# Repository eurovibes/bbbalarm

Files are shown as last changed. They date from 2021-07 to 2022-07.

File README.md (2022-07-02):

<!-- SPDX-FileCopyrightText: 2021 Benedikt Spranger <b.spranger@linutronix.de> -->
<!-- SPDX-License-Identifier: CERN-OHL-S-2.0 -->


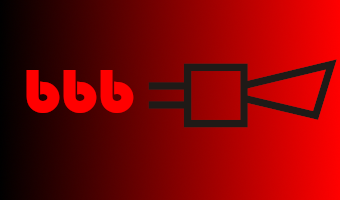
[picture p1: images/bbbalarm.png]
bbbalarm logo


# bbbalarm - An Alarm cape for Beaglebone Black

The Beaglobone Black is a TI Sitara AM3359 ARM Cortex-A8 CPU based
evaluation board with two 40pin 100mil pinsockets. These pinsockets
can be used for additional functionality boards called capes.
The bbbalarm cape enhance the Beaglebone Black by adding coupled and
decoupled inputs, that can be used to supervise an air condition or read out
a presence detector.

## License rules

bbbalarm is provided under the terms of the CERN-OHL-S license version 2 as
provided in the LICENSES/CERN-OHL-S-2.0 file.

Instead of adding license boilerplates to the individual files, bbbalarm uses
SPDX license identifiers, which are machine parseable and considered legaly
equivalent.

The SPDX license identifier in bbbalarm shall be added at the first possible
line in a file which can contain a comment. This is normally the first line
except for scripts. Scripts require the #!PATH_TO_INTERPRETER tag in the
first line; place the SPDX identifier into the second line.

The SPDX license identifier is added in form of a comment.

## Copyright and License

Copyright Benedikt Spranger 2021.
This source describes Open Hardware and is licensed under the CERNOHL-S v2.
You may redistribute and modify this source and make products using it
under the terms of the CERN-OHL-S v2
(https://ohwr.org/cern ohl s v2.txt ).
This source is distributed WITHOUT ANY EXPRESS OR IMPLIED
WARRANTY, INCLUDING OF MERCHANTABILITY, SATISFACTORY
QUALITY AND FITNESS FOR A PARTICULAR PURPOSE. Please see
the CERN-OHL-S v2 for applicable conditions.
Source location: https://github.com/eurovibes/bbbalarm
As per CERN-OHL-S v2 section 4, should You produce hardware based
on this source, You must where practicable maintain the Source Location
visible on the external case of the bbbalarm or other products you make using
this source.

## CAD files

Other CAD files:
logo.FCStd

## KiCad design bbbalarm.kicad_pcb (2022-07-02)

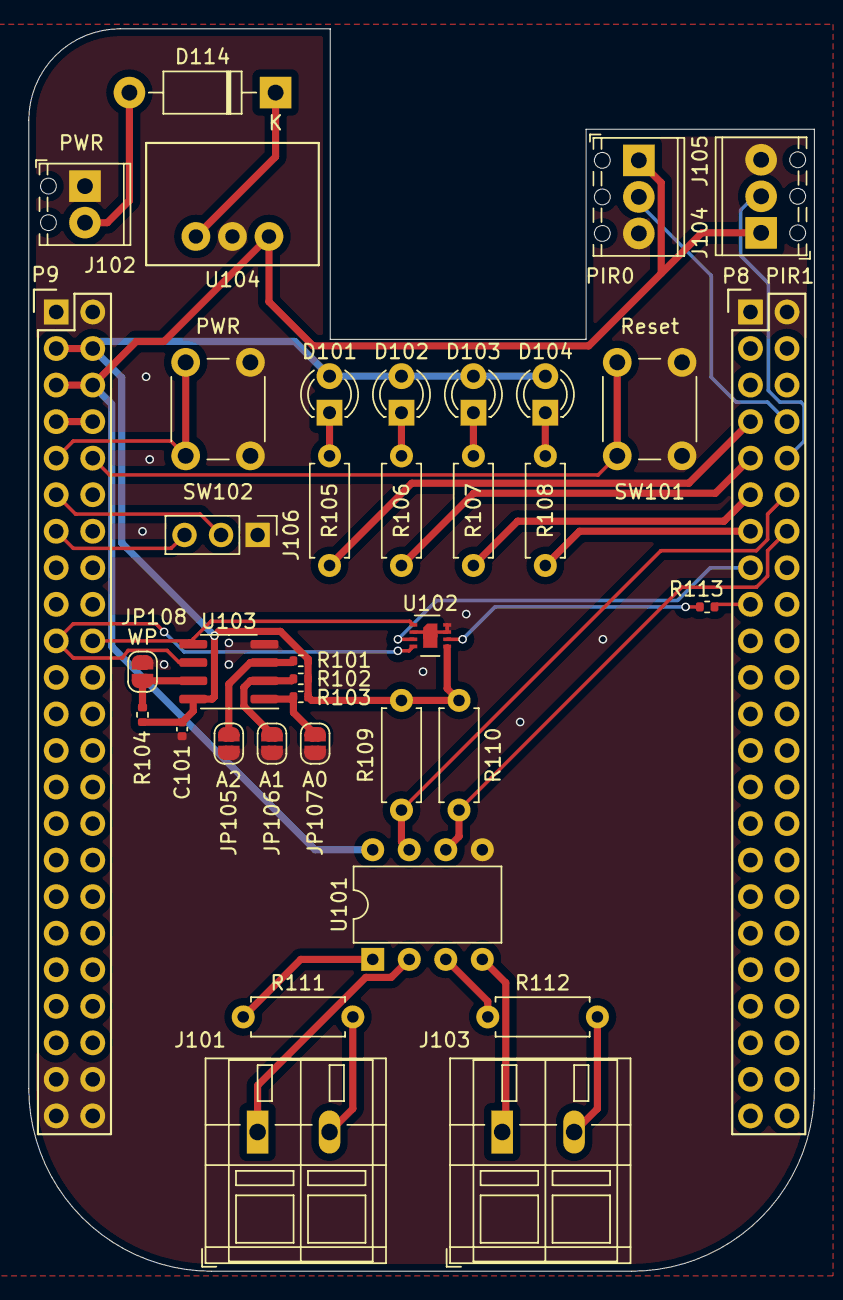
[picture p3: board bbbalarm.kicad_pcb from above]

Board: 2 copper layers, 54.6 x 86.4 mm, 37 parts (0 on the bottom side), 37 nets.

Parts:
C101: 100n; C_0402_1005Metric
D101, D102, D103, D104: LED; LED_D3.0mm
D114: 1N4004; D_DO-41_SOD81_P10.16mm_Horizontal
J101: IN0; TerminalBlock_WAGO_236-102_1x02_P5.00mm_45Degree
J102: PWR; TerminalBlock_Phoenix_MPT-0,5-2-2.54_1x02_P2.54mm_Horizontal
J103: IN1; TerminalBlock_WAGO_236-102_1x02_P5.00mm_45Degree
J104: PIR0; TerminalBlock_Phoenix_MPT-0,5-3-2.54_1x03_P2.54mm_Horizontal
J105: PIR1; TerminalBlock_Phoenix_MPT-0,5-3-2.54_1x03_P2.54mm_Horizontal
J106: serial; PinHeader_1x03_P2.54mm_Vertical
JP105: A2; SolderJumper-2_P1.3mm_Open_RoundedPad1.0x1.5mm
JP106: A1; SolderJumper-2_P1.3mm_Open_RoundedPad1.0x1.5mm
JP107: A0; SolderJumper-2_P1.3mm_Open_RoundedPad1.0x1.5mm
JP108: WP; SolderJumper-2_P1.3mm_Open_RoundedPad1.0x1.5mm
P8, P9: BeagleBone_Black_Header; Socket_BeagleBone_Black
R101, R102, R103, R104, R113: 1k; R_0402_1005Metric
R105, R106, R107, R108, R109, R110: 1k; R_Axial_DIN0207_L6.3mm_D2.5mm_P7.62mm_Horizontal
R111, R112: 330; R_Axial_DIN0207_L6.3mm_D2.5mm_P7.62mm_Horizontal
SW101: Reset; SW_PUSH_6mm
SW102: PWR; SW_PUSH_6mm
U101: HCPL-263N; DIP-8_W7.62mm
U102: SHT35-DIS; Sensirion_DFN-8-1EP_2.5x2.5mm_P0.5mm_EP1.1x1.7mm
U103: AT24C512C-SSHD-T; SOIC-8_3.9x4.9mm_P1.27mm
U104: WPMDH1100xx1S

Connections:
+3V3: C101.1, D101.2 (A), D102.2 (A), D103.2 (A), D104.2 (A), P9.3, P9.4, R101.1, R102.1, R103.1, R104.1, R109.1, R110.1, U102.5 (VDD), U103.8 (VCC)
+5V: J104.1, J105.1, P9.5, P9.6, U101.8 (VCC), U104.3 (Vout)
/ALERT: P8.15, U102.3 (ALERT)
/IN0: P8.12, R109.2, U101.7 (VO1)
/IN1: P8.14, R110.2, U101.6 (VO2)
/LED0: P8.7, R105.2
/LED1: P8.9, R106.2
/LED2: P8.11, R107.2
/LED3: P8.13, R108.2
/PIR0: J104.2, P8.8
/PIR1: J105.2, P8.10
/RX: J106.2, P9.11
/SCL: P9.19, U102.4 (SCL), U103.6 (SCL)
/SDA: P9.20, U102.1 (SDA), U103.5 (SDA)
/TX: J106.3, P9.13
/nRST: P8.17, R113.1
GNDD: C101.2, J102.1, J104.3, J105.3, J106.1, JP105.2 (B), JP106.2 (B), JP107.2 (B), JP108.2 (B), P8.1, P8.2, P9.1, P9.2, P9.43, P9.44, P9.45, P9.46, SW101.2, SW102.2, U101.5 (GND), U102.2 (ADDR), U102.7 (R), U102.8 (VSS), U102.9 (VSS), U103.4 (GND), U104.2 (GND)
unnamed: D101.1 (K), R105.1
unnamed: D102.1 (K), R106.1
unnamed: D103.1 (K), R107.1
unnamed: D104.1 (K), R108.1
unnamed: D114.1 (K), U104.1 (Vin)
unnamed: D114.2 (A), J102.2
unnamed: J101.1, U101.2 (C1)
unnamed: J101.2, R111.2
unnamed: J103.1, U101.4 (A2)
unnamed: J103.2, R112.2
unnamed: JP105.1 (A), R101.2, U103.3 (A2)
unnamed: JP106.1 (A), R102.2, U103.2 (A1)
unnamed: JP107.1 (A), R103.2, U103.1 (A0)
unnamed: JP108.1 (A), R104.2, U103.7 (WP)
unnamed: R111.1, U101.1 (A1)
unnamed: R112.1, U101.3 (C2)
unnamed: R113.2, U102.6 (~RESET)
PWR_BUT: P9.9, SW102.1
SYS_5V: P9.7, P9.8
SYS_RESETN: P9.10, SW101.1

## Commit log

2022-07-02 Update to KiCAD v6
    [bbbalarm.kicad_pcb, bbbalarm.kicad_sch, bbbalarm.sch]
2022-07-02 Add Temp sensor and serial header
    [bbbalarm.kicad_pcb, bbbalarm.kicad_sch]
2022-07-02 CI: Rework HTML BOM
2022-07-02 Revisit Parts
    [bbbalarm.kicad_sch]

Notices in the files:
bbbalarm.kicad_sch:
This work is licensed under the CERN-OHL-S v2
